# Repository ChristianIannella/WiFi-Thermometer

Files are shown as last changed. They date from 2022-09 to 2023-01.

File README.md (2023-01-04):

# WiFi-Thermometer

Italiano/English

WiFi Thermometer è un dispositivo IoT pronto all'uso ma con la possibilità di cambiare firmware in modo semplice tramite connettore dedicato.

A bordo è presente un AC/DC (RAC02-3.3SGB), un ESP8266 (mod. ESP12) e un sensore di temperatura/umidità (HTU21D).
Ti basterà alimentare la scheda tramite il connettore a morsetti direttamente alla tensione di rete oppure tramite pin 1 (GND) e pin 6 (3.3v) del
connettore per la programmazione.
ATTENZIONE! NON ALIMENTARE LA SCHEDA CON I DUE METODI CONTEMPORANEAMENTE.
Per aggiornare o cambiare il firmware avrai bisogno del programmatore o un convertitore USB/UART come il CH340G ATTENZIONE! IL CONVERTITORE DEVE LAVORARE A 3.3V

PINOUT

1: GND

2: GPIO2

3: GPIO0

4: RX

5: TX

6: VCC 3.3v

COME FUNZIONA

Al momento dell accensione se non è stato gia configurato il dispositivo metterà a disposizione un access point (SSID: WiFi Thermometer, Password:12345678)
tramite il quale sara possibile inserire SSID e Password della propria rete lan.

You can find WiFi Thermometer on Tindie

(This page is work in progress!)

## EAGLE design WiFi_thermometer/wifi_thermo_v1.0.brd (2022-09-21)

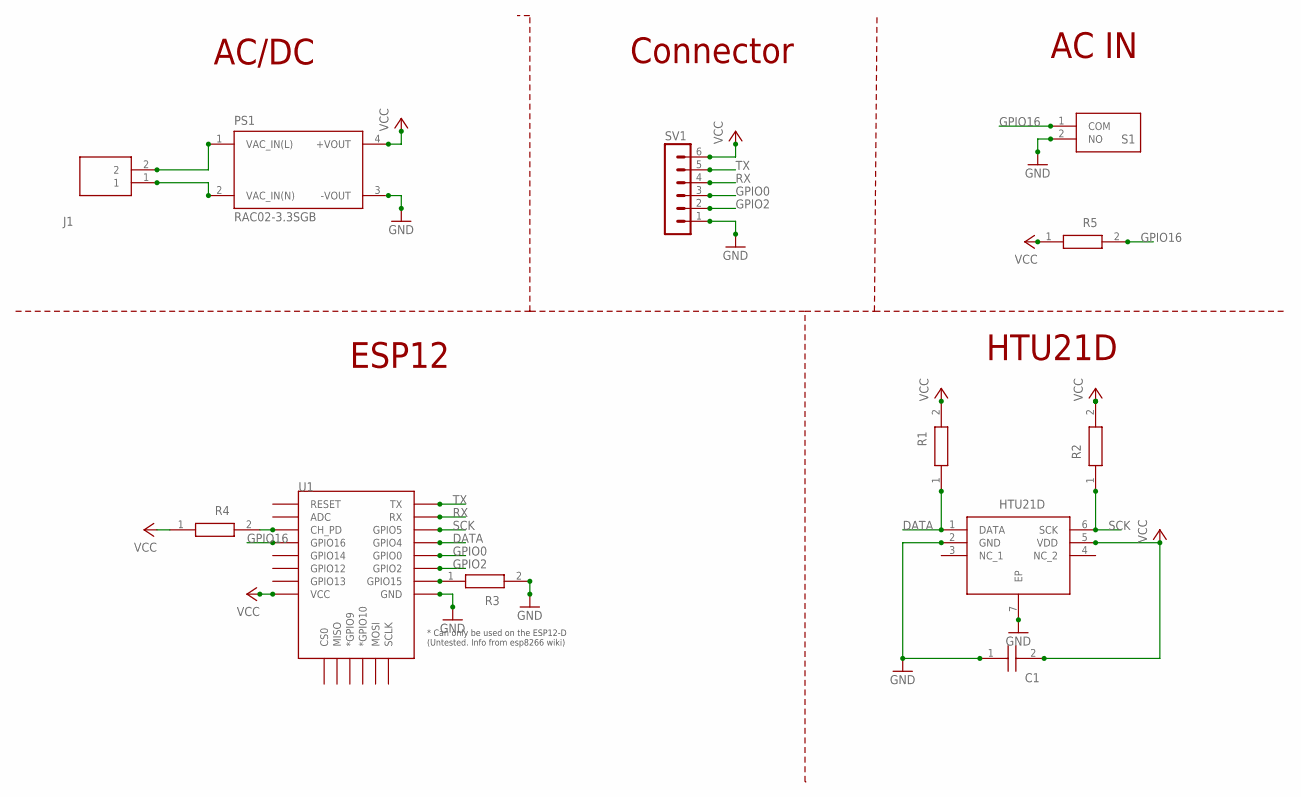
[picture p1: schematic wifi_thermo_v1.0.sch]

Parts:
C1: C1206C104J3GEC7210; CAPC3216X110N
HM1: HTU21D; SON100P300X300X100-7N
J1: TB006-508-02BE; TB00650802BE
PS1: RAC02-3.3SGB; CONV_RAC02-3.3SGB
R1, R2, R3, R4, R5: RT1206FRD0710KL; RESC3116X65N
S1: PTS636_SP50_SMTR_LFS; PTS636SP50SMTRLFS
SV1: MA06-1
U1: ESP12ESMD; ESP12E-SMD

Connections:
DATA: HM1.1 (DATA), R1.1, U1.GPIO4
GND: C1.1, HM1.2 (GND), HM1.7 (EP), PS1.3 (-VOUT), R3.2, S1.2 (NO), SV1.1, U1.GND
GPIO0: SV1.3, U1.GPIO0
GPIO2: SV1.2, U1.GPIO2
GPIO16: R5.2, S1.1 (COM), U1.GPIO16
unnamed: J1.2, PS1.1 (VAC_IN(L))
unnamed: J1.1, PS1.2 (VAC_IN(N))
unnamed: R3.1, U1.GPIO15
unnamed: R4.2, U1.CH_PD
RX: SV1.4, U1.RXD0 (RX)
SCK: HM1.6 (SCK), R2.1, U1.GPIO5
TX: SV1.5, U1.TXD0 (TX)
VCC: C1.2, HM1.5 (VDD), PS1.4 (+VOUT), R1.2, R2.2, R4.1, R5.1, SV1.6, U1.VCC

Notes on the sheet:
AC/DC
Connector
AC IN
HTU21D
ESP12

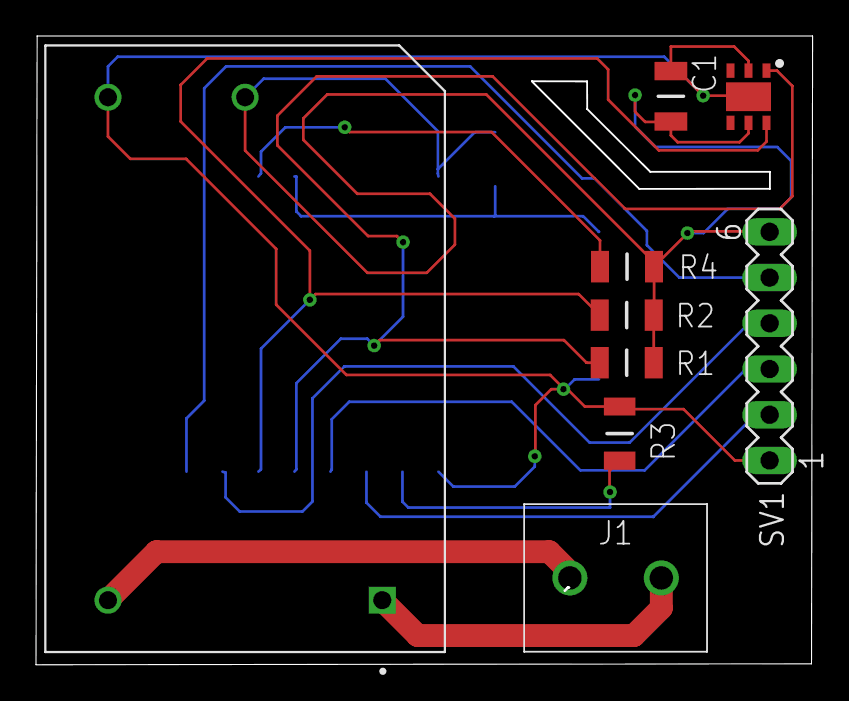
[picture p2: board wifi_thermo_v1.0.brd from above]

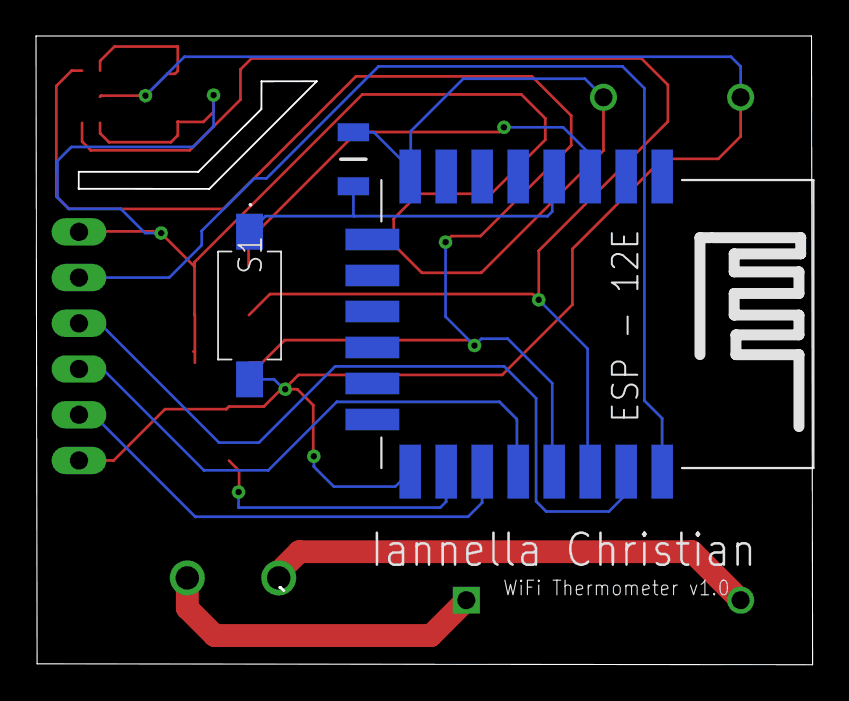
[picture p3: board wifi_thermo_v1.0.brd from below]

Board: 2 copper layers, 43.1 x 34.9 mm, 12 parts (3 on the bottom side), 13 nets.

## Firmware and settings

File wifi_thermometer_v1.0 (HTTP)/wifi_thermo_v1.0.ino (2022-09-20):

#include "Arduino.h"
#include <Wire.h>
#include "SparkFunHTU21D.h"
#include <ESP8266WiFi.h>
#include <WiFiClient.h>
#include <DNSServer.h>
#include <ESP8266WebServer.h>
#include <ESP8266mDNS.h>

#include "setup.h"
#include "pag1.h"
#include "pag2.h"
#include "pag_info.h"
#include "wifi_station.h"

HTU21D myHumidity;

bool ap_mode = false;
const int ledpin = 2;
const int resetpin = 16;
unsigned long previousMillis = 0;
const long interval_ap = 1500;
const long interval_connection = 500;

char text[] = "    ";

void setup()
{
  pinMode(resetpin, INPUT_PULLUP);
  pinMode(ledpin, OUTPUT);
  digitalWrite(ledpin, HIGH);
  myHumidity.begin();
  delay(500);
  check_config();
}

void loop()
{
  dnsServer.processNextRequest();
  MDNS.update();
  server.handleClient();
  webserver.handleClient();
  ap_blink();
  conf_reset();
}

void read_temp()
{
  int h = myHumidity.readHumidity();
  int t = myHumidity.readTemperature();

  sprintf(text, (PGM_P)F("%02d-%02d"), t, h);
}

void ap_blink()
{
  unsigned long currentMillis = millis();
  if (currentMillis - previousMillis >= interval_ap)
  {
    previousMillis = currentMillis;
    if (ap_mode == true)
    {
      digitalWrite(ledpin, LOW);
      delay(10);
    }
  }
  if (ap_mode == true)
  {
    digitalWrite(ledpin, HIGH);
  }
}

void connection_blink()
{
  unsigned long currentMillis = millis();
  if (currentMillis - previousMillis >= interval_connection)
  {
    previousMillis = currentMillis;
    digitalWrite(ledpin, LOW);
    delay(10);
    digitalWrite(ledpin, HIGH);
  }
}

void conf_reset()
{
  if (digitalRead(resetpin) == LOW)
  {
    for (int i = 0; i <= 10; i++)
    {
      digitalWrite(ledpin, LOW);
      delay(50);
      digitalWrite(ledpin, HIGH);
      delay(50);
    }
    LittleFS.format();
    ESP.restart();
  }
}
